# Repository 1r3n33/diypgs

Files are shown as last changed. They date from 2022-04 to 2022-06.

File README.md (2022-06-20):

# diypgs 🎮

The DIY portable game system.



# Electronics (schematics, PCB) 🪛🧰

Easy, cheap, and Arduino based...

### 👉 [**Making of the 1st board explained with pictures!**](./make/README.md) 📷

---

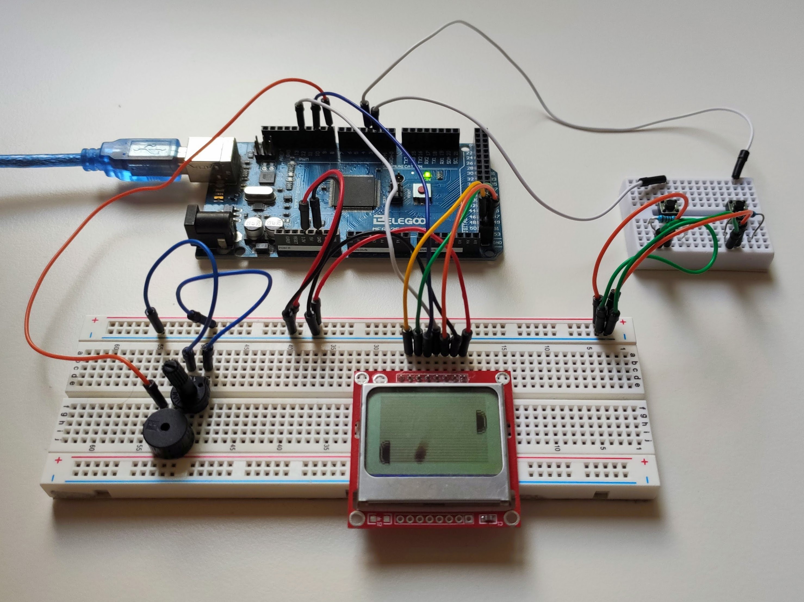
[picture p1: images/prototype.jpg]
Prototype

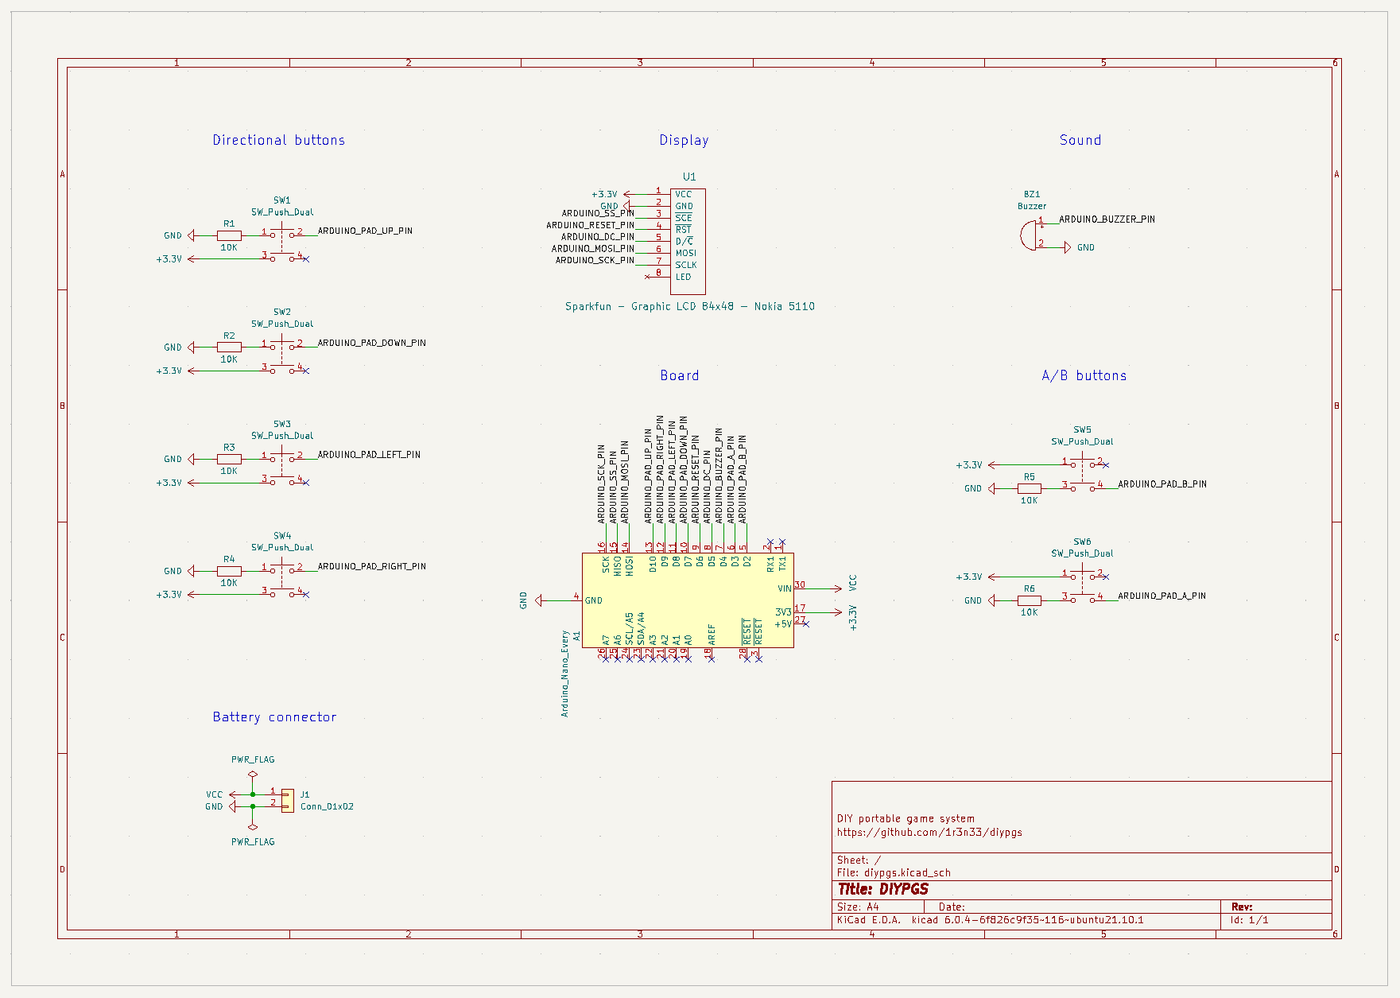
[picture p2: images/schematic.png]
Schematic

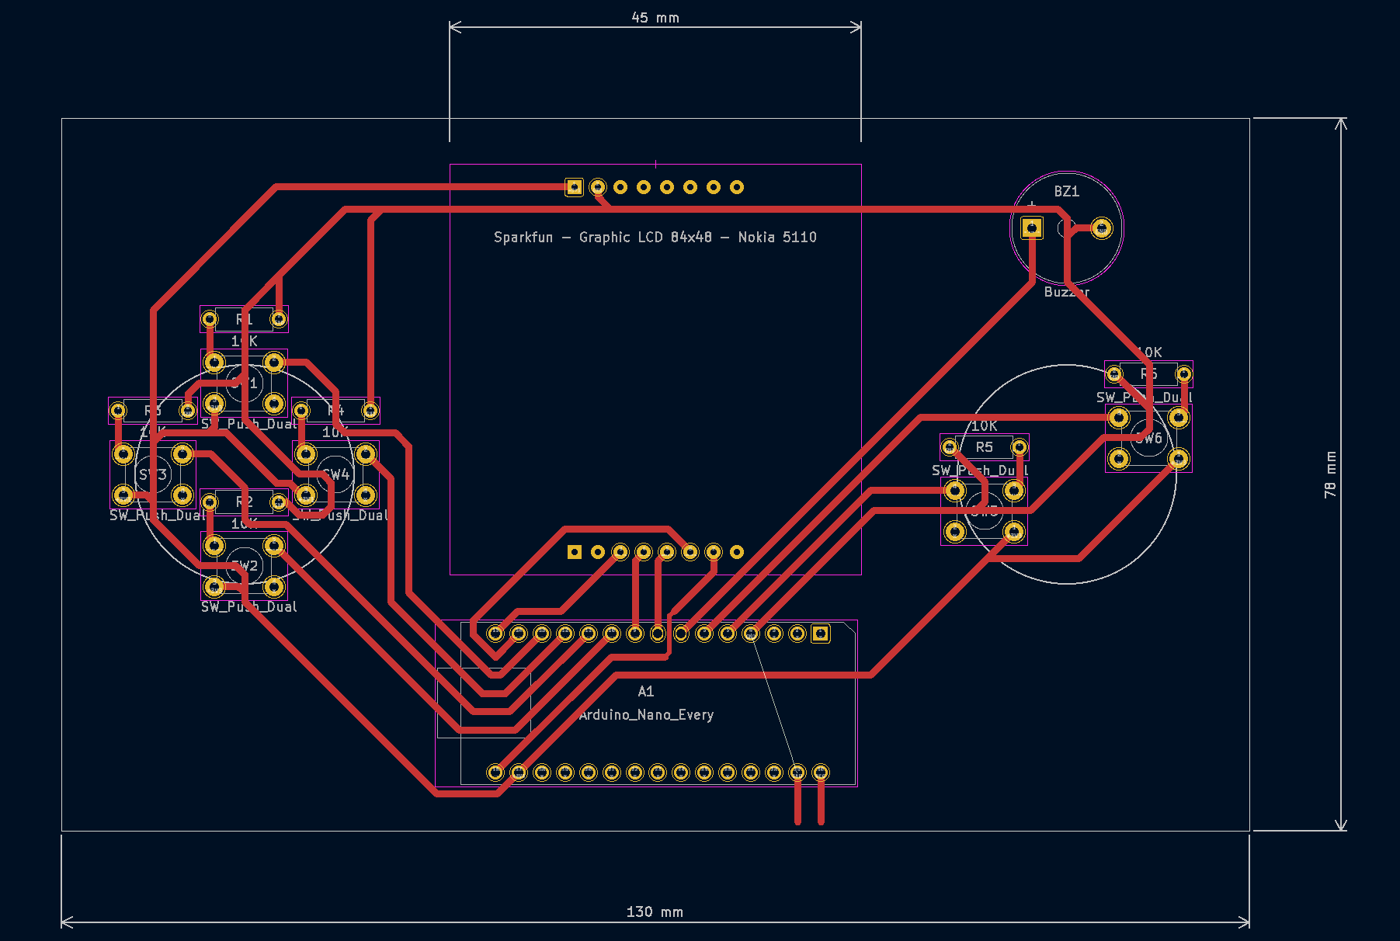
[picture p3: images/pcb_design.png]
PCB_Design

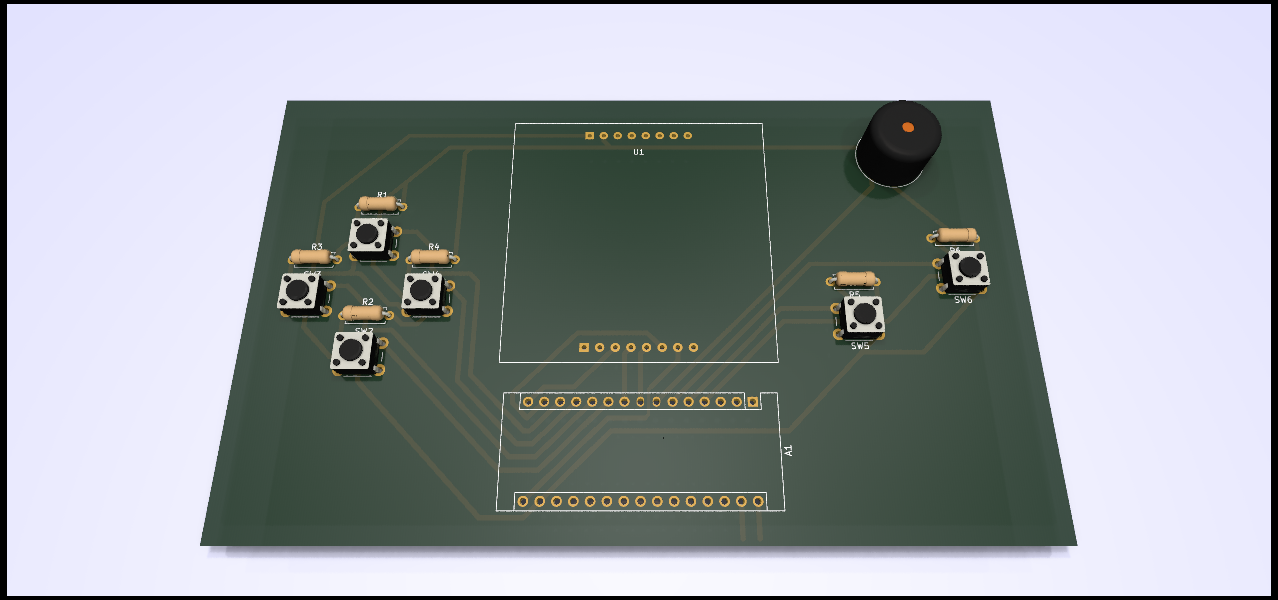
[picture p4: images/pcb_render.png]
PCB_Render


# Software (development kit & games) 🧑‍💻🤖

Develop your own games with provided SDK and example!

# 3D printing (case) 🚧👷

TBD

# Shop 🛒💸

If you are interested in getting one, please contact icaroulle+diypgs@gmail.com.

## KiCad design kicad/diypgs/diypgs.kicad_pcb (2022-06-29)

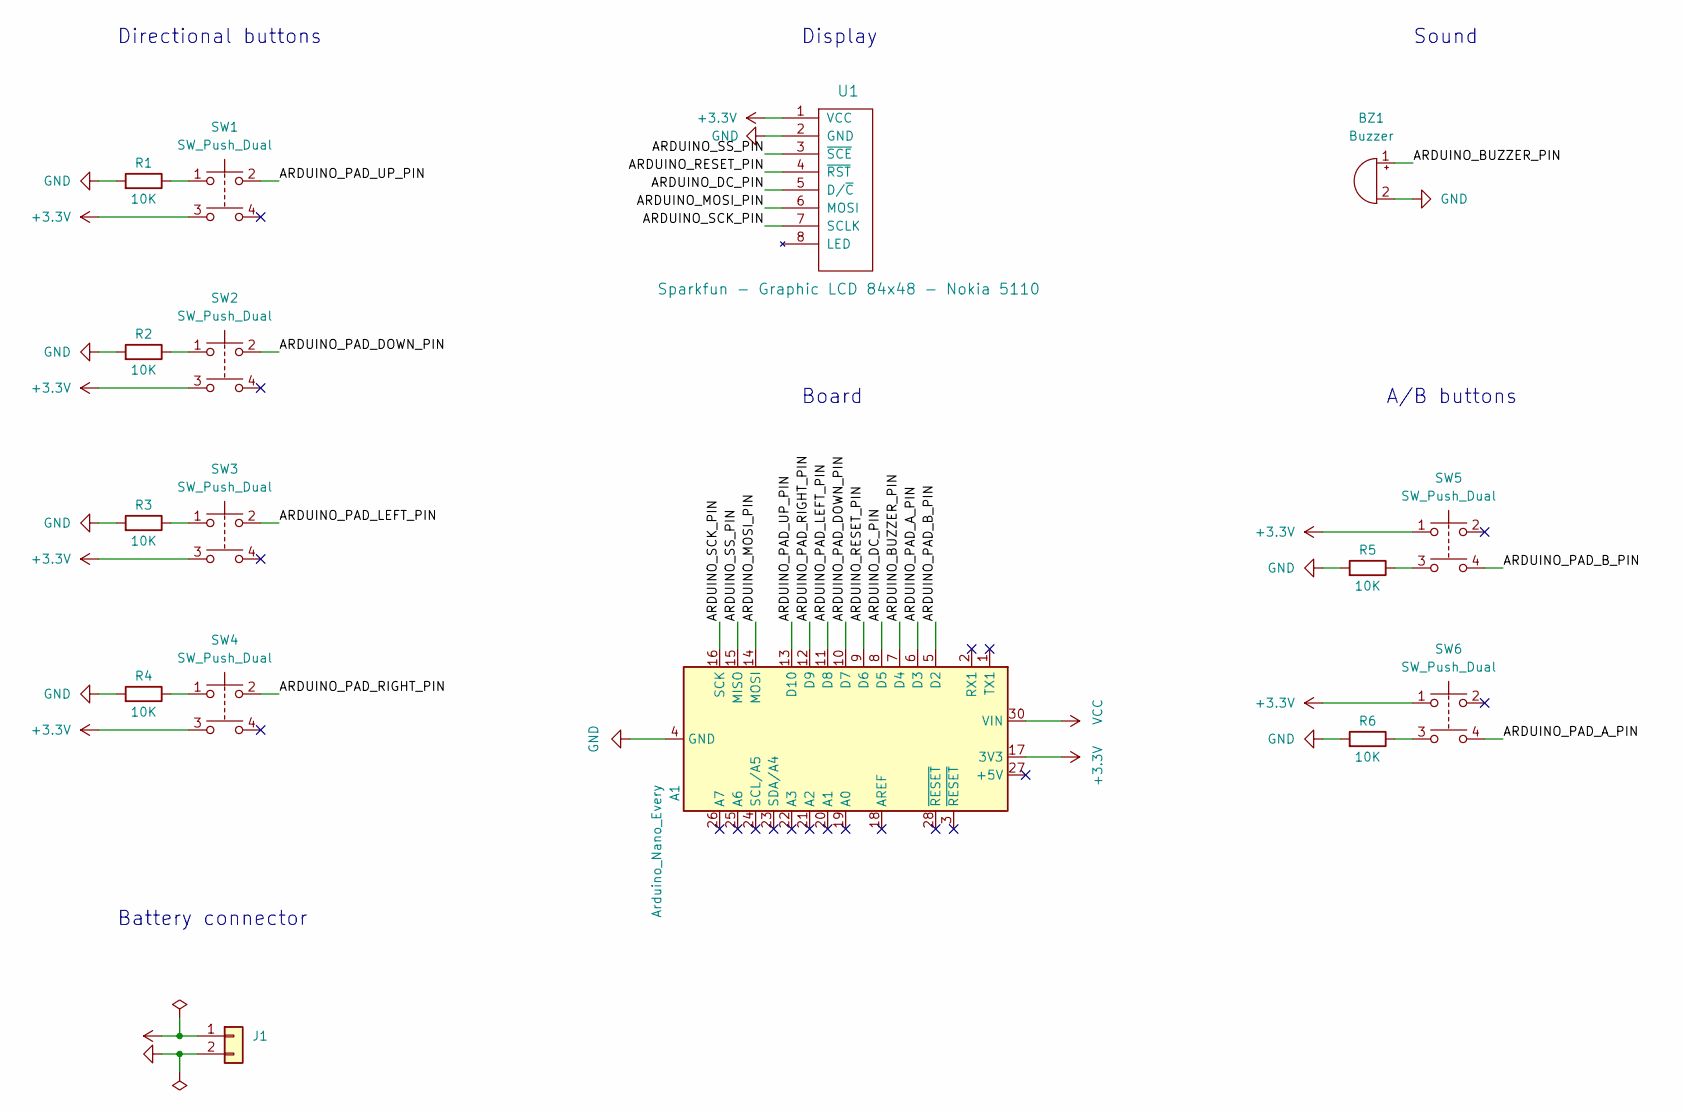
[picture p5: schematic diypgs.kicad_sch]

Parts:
A1: Arduino_Nano_Every; Arduino_Nano
BZ1: Buzzer; Buzzer_12x9.5RM7.6
J1: (no value)
R1, R2, R3, R4, R5, R6: 10K; R_Axial_DIN0207_L6.3mm_D2.5mm_P7.62mm_Horizontal
SW1, SW2, SW3, SW4, SW5, SW6: SW_Push_Dual; SW_PUSH_6mm_ALT
U1: Sparkfun - Graphic LCD 84x48 - Nokia 5110

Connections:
+3V3: A1.17 (3V3), SW1.3, SW2.3, SW3.3, SW4.3, SW5.1, SW6.1, U1.1 (VCC)
/ARDUINO_BUZZER_PIN: A1.7 (D4), BZ1.1 (-)
/ARDUINO_DC_PIN: A1.8 (D5), U1.5 (D/~C)
/ARDUINO_MOSI_PIN: A1.14 (MOSI), U1.6 (MOSI)
/ARDUINO_PAD_A_PIN: A1.6 (D3), SW6.4
/ARDUINO_PAD_B_PIN: A1.5 (D2), SW5.4
/ARDUINO_PAD_DOWN_PIN: A1.10 (D7), SW2.2
/ARDUINO_PAD_LEFT_PIN: A1.11 (D8), SW3.2
/ARDUINO_PAD_RIGHT_PIN: A1.12 (D9), SW4.2
/ARDUINO_PAD_UP_PIN: A1.13 (D10), SW1.2
/ARDUINO_RESET_PIN: A1.9 (D6), U1.4 (~RST)
/ARDUINO_SCK_PIN: A1.16 (SCK), U1.7 (SCLK)
/ARDUINO_SS_PIN: A1.15 (MISO), U1.3 (~SCE)
GND: A1.4 (GND), A1.29 (GND), BZ1.2 (+), R1.2, R2.2, R3.2, R4.2, R5.2, R6.2, U1.2 (GND)
unnamed: J1.1, J1.2
unnamed: R1.1, SW1.1
unnamed: R2.1, SW2.1
unnamed: R3.1, SW3.1
unnamed: R4.1, SW4.1
unnamed: R5.1, SW5.3
unnamed: R6.1, SW6.3
VCC: A1.30 (VIN)

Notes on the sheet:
Sound
Display
A/B buttons
Directional buttons
Battery connector
Board

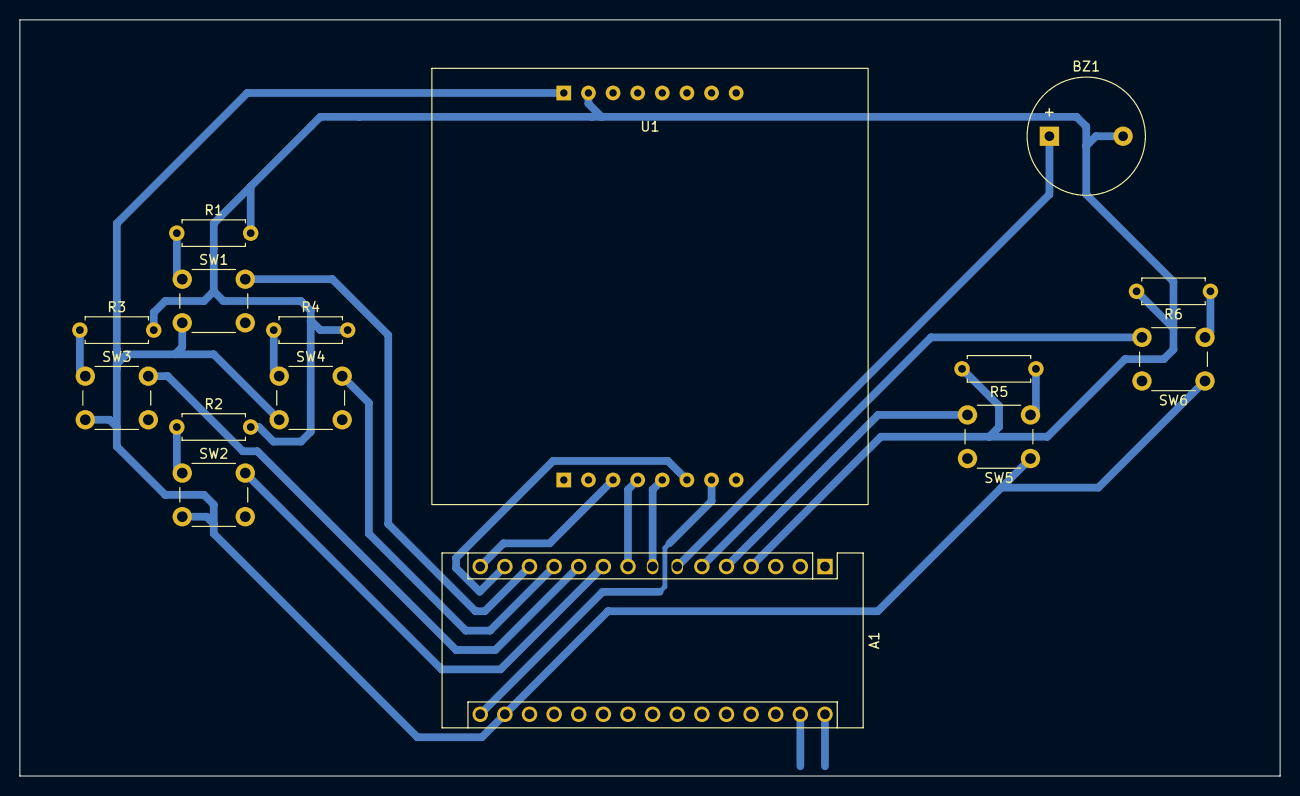
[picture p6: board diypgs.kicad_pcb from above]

Board: 2 copper layers, 130.0 x 78.0 mm, 15 parts (0 on the bottom side), 20 nets.

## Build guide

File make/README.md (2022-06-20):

# Making your own PCB

## Toner transfer

PCB circuit layer laser printed on glossy paper:  
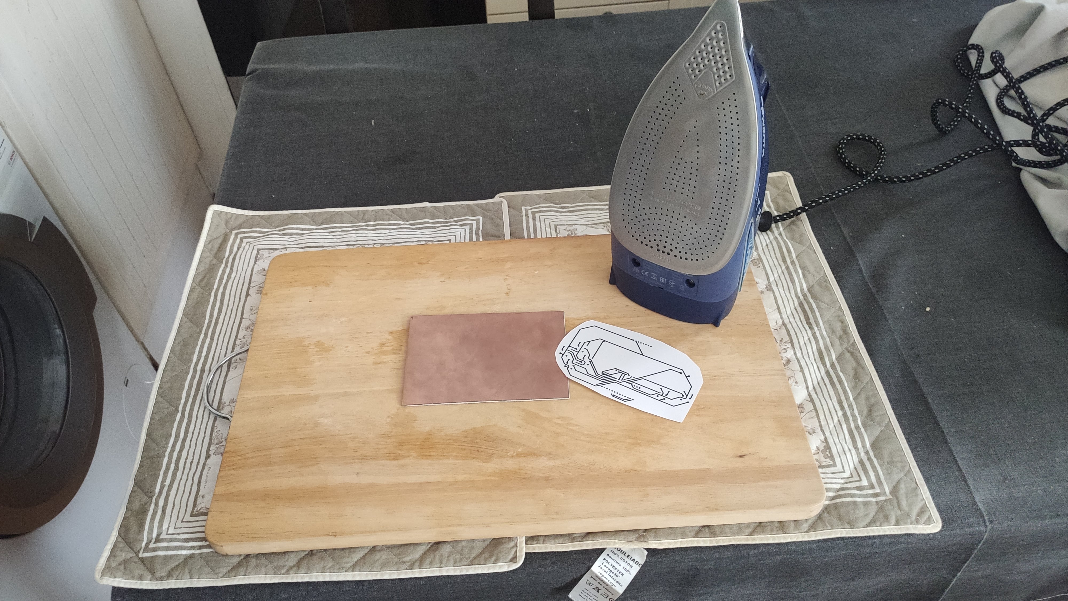
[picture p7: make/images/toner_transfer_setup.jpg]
TonerTransferSetup


Maximum heat and apply strong pressure to transfer toner (5 min.):
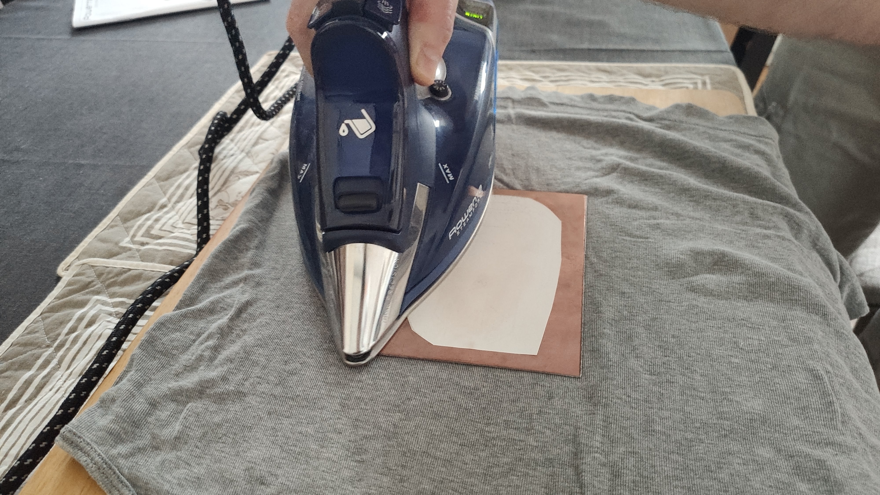
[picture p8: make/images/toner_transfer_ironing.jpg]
TonerTransferIroning


Water bath to remove the paper (10 min.):
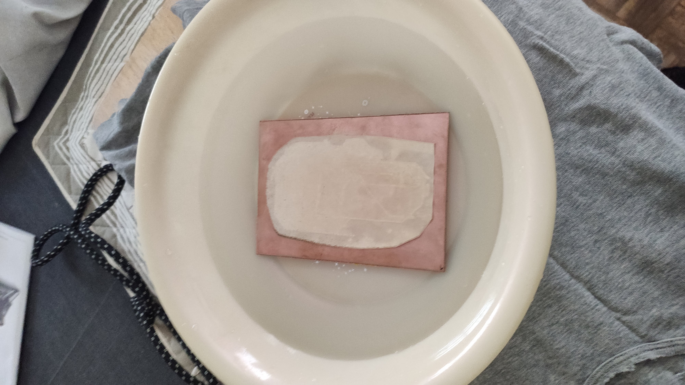
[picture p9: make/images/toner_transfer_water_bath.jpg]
TonerTransferWaterBath


Peel the paper gently:
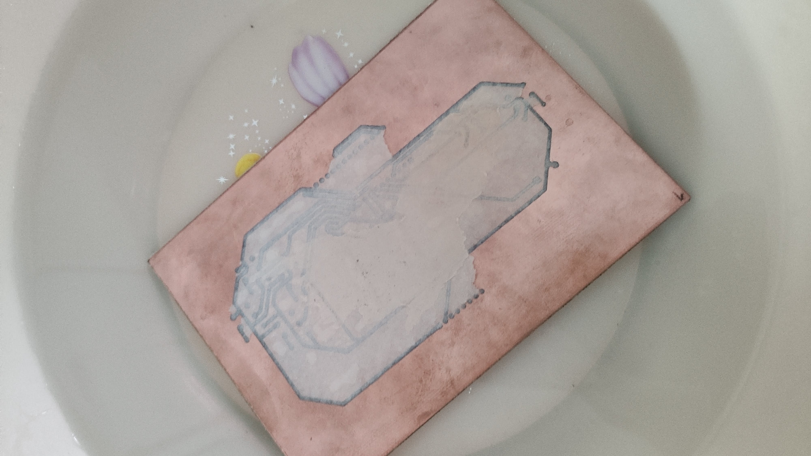
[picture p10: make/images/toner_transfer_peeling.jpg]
TonerTransferPeeling


Toner acts as a mask when chemically removing the copper:
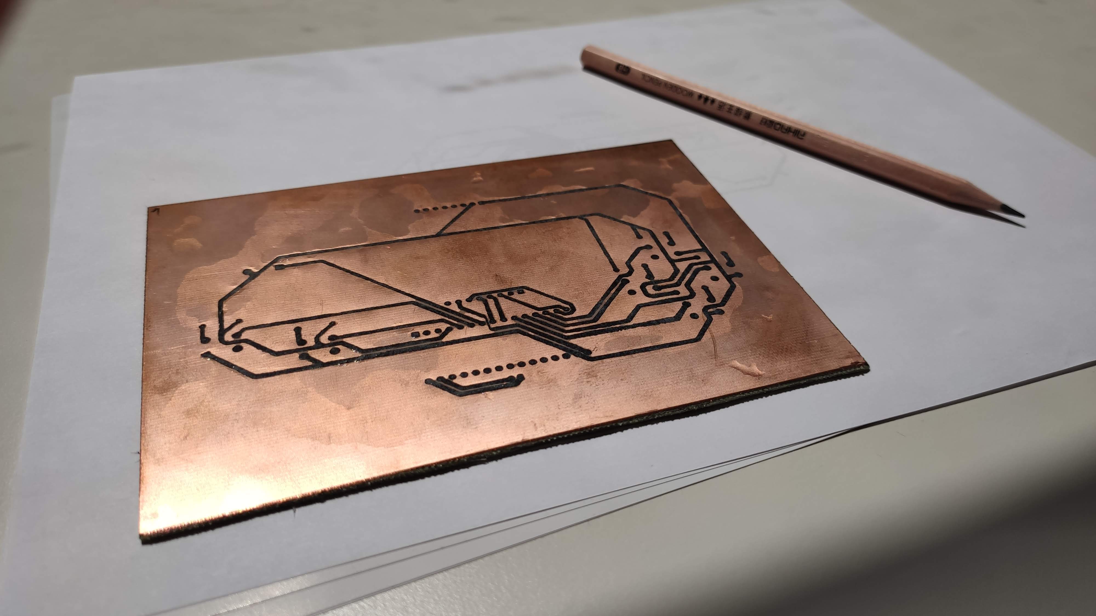
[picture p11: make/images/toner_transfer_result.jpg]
TonerTransferResult


## Etching

Bath the PCB in ferric chloride and gently agitate the solution in a well-ventilated area (45 min.):
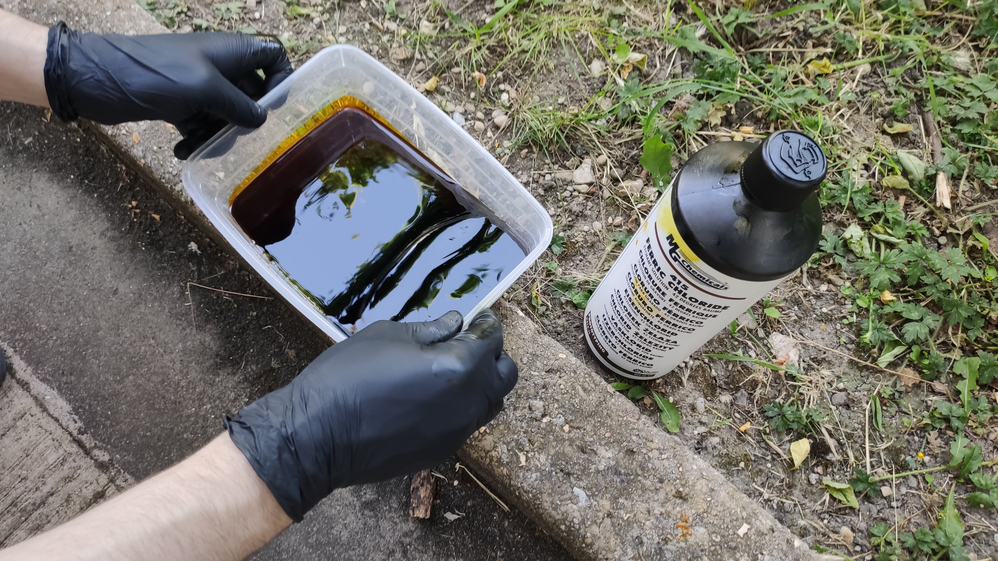
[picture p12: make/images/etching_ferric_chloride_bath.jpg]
EtchingFerricChlorideBath


Wash many times in water:
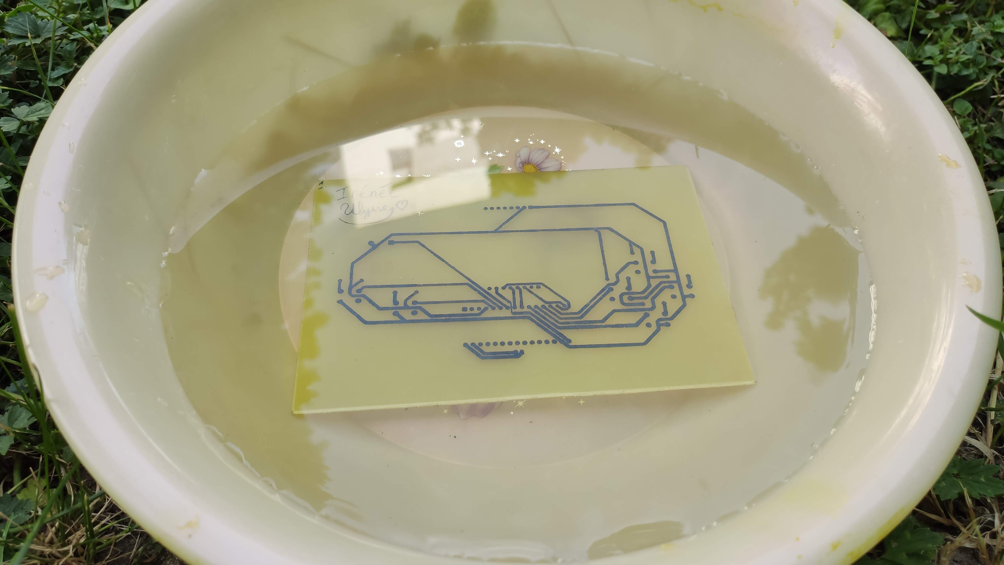
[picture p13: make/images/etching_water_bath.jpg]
EtchingWaterBatch


## Cleaning

Remove toner with acetone in a well-ventilated area:
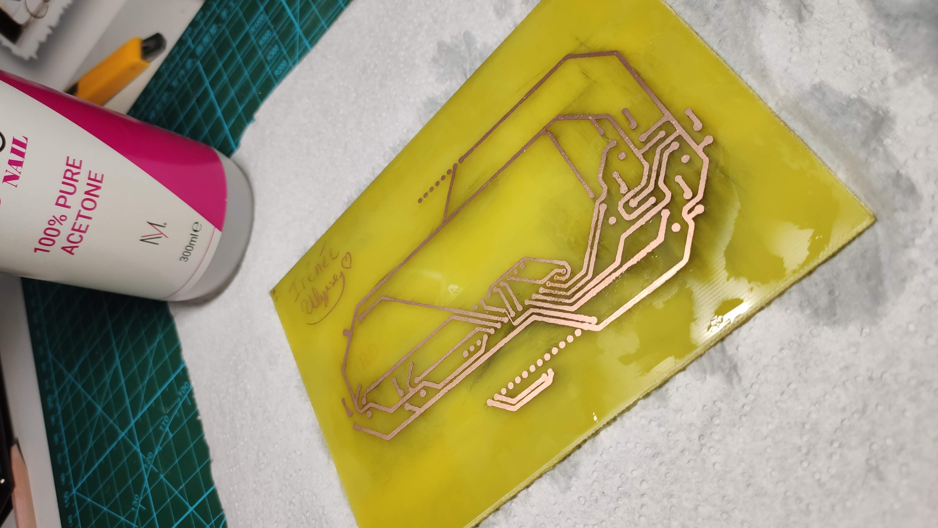
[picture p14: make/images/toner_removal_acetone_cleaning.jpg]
TonerRemovalAcetoneCleaning


Ready to be tested:
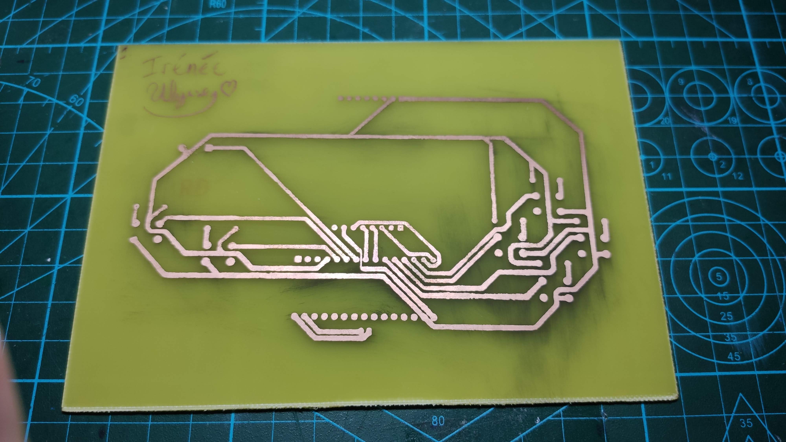
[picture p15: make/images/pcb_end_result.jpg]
PcbEndResult


## Testing

Checking and fixing short circuits:
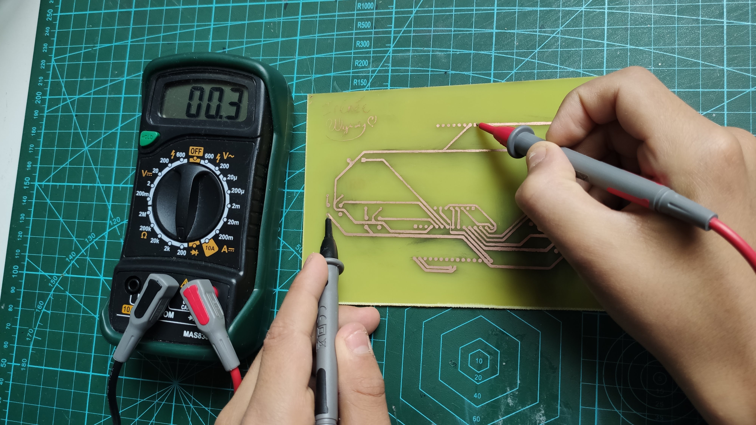
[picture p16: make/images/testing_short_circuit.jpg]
TestingShortCircuit


## Mounting & soldering

Getting ready to mount the board:
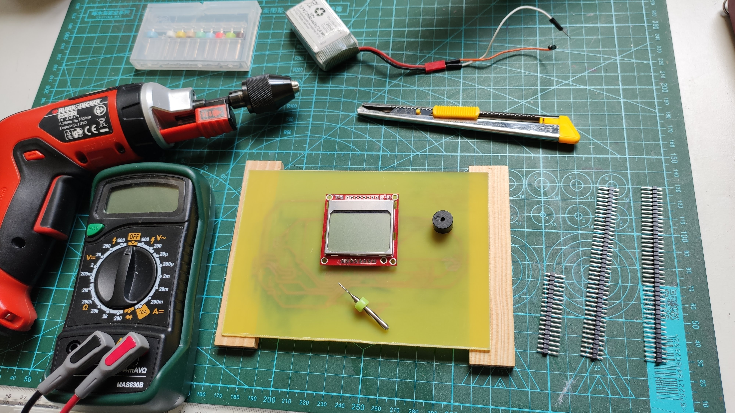
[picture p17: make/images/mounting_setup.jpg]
MountingSetup


Main components soldered:
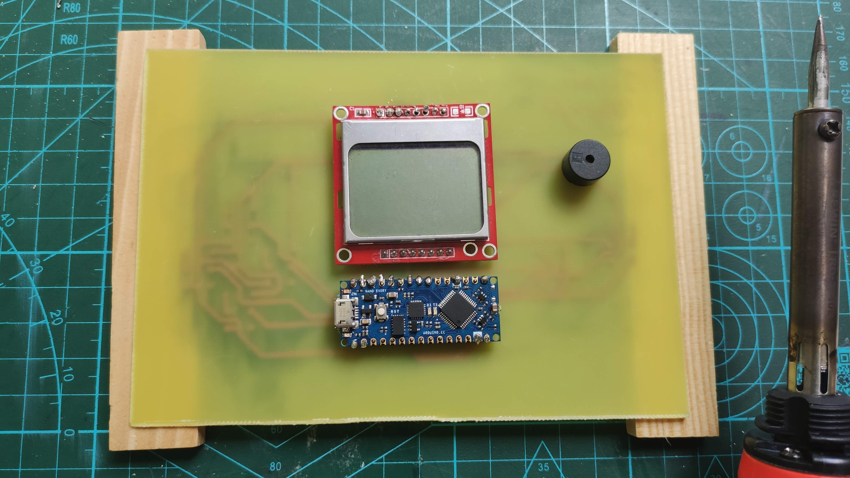
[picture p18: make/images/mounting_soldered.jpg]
MountingSoldered


Booting up:
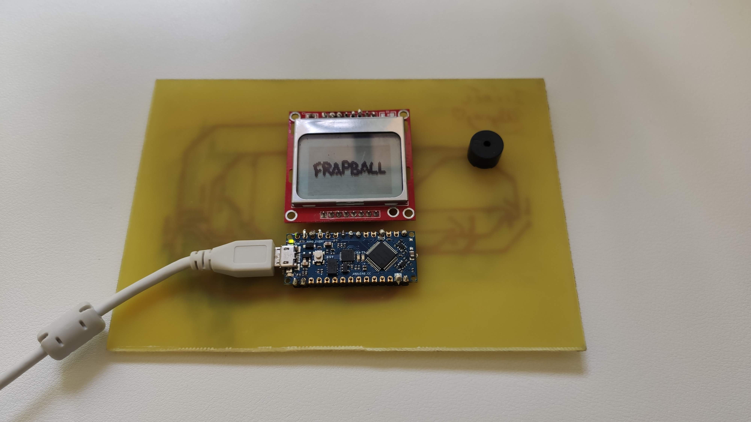
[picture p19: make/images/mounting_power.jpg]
MountingPower


## Playing

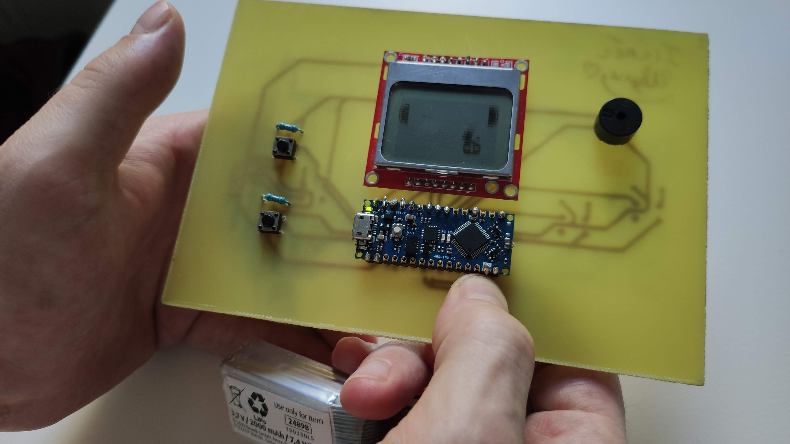
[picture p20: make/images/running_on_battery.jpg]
RunningOnBattery


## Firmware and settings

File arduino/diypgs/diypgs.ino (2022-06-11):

#include "src/hw/Buzzer.h"
#include "src/hw/Gamepad.h"
#include "src/hw/Pcd8544.h"

#include "src/sdk/Collision.h"

#include "src/game/Game.h"
#include "src/game/Titlescreen.h"

namespace
{
  constexpr uint32_t USEC_PER_FRAME = 1000000 / 30; // 30 Hz

  const hw::Pcd8544 graphics(5, 6, 12);
  const hw::Buzzer audio(4);
  const hw::Gamepad controller(10, 7, 8, 9, 3, 2);

  game::Titlescreen titlescreen(graphics, audio, controller);
  game::Game game_(graphics, audio, controller);

  game::World *currentWorld = nullptr;
}

void setup()
{
  srand(micros());

  graphics.setup();
  audio.setup();
  controller.setup();

  titlescreen.setNextWorld(&game_);
  game_.setNextWorld(&titlescreen);

  currentWorld = &titlescreen;
  currentWorld->setup();
}

void loop()
{
  const uint32_t start = micros();

  game::World::State state = currentWorld->update();
  graphics.render();

  game::World *nextWorld = nullptr;
  switch (state)
  {
  case game::World::State::NEXT:
    nextWorld = currentWorld->getNextWorld();
    nextWorld->setup();
    currentWorld = nextWorld;
    break;

  default:
    break;
  }

  // Target 30 fps.
  // Cannot use delayMicroseconds because the largest value that will produce an accurate delay is 16383.
  // https://www.arduino.cc/reference/en/language/functions/time/delaymicroseconds/
  const uint32_t elapsed = micros() - start;
  if (elapsed < USEC_PER_FRAME)
  {
    delay((USEC_PER_FRAME - elapsed) / 1000);
  }
}

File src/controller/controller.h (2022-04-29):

#ifndef CONTROLLER_H
#define CONTROLLER_H

class Controller
{
private:
    uint8_t pins[6];

public:
    static const uint8_t BUTTON_UP = 0x01;
    static const uint8_t BUTTON_DOWN = 0x02;
    static const uint8_t BUTTON_LEFT = 0x04;
    static const uint8_t BUTTON_RIGHT = 0x08;
    static const uint8_t BUTTON_A = 0x10;
    static const uint8_t BUTTON_B = 0x20;

    Controller()
    {
    }

    void setup(const uint8_t button_up_pin,
               const uint8_t button_down_pin,
               const uint8_t button_left_pin,
               const uint8_t button_right_pin,
               const uint8_t button_a_pin,
               const uint8_t button_b_pin)
    {
        pins[0] = button_up_pin;
        pins[1] = button_down_pin;
        pins[2] = button_left_pin;
        pins[3] = button_right_pin;
        pins[4] = button_a_pin;
        pins[5] = button_b_pin;

        pinMode(pins[0], INPUT);
        pinMode(pins[1], INPUT);
        pinMode(pins[2], INPUT);
        pinMode(pins[3], INPUT);
        pinMode(pins[4], INPUT);
        pinMode(pins[5], INPUT);
    }

    uint8_t get() const
    {
        uint8_t out = 0;
        out |= digitalRead(pins[0]) == HIGH ? BUTTON_UP : 0;
        out |= digitalRead(pins[1]) == HIGH ? BUTTON_DOWN : 0;
        out |= digitalRead(pins[2]) == HIGH ? BUTTON_LEFT : 0;
        out |= digitalRead(pins[3]) == HIGH ? BUTTON_RIGHT : 0;
        out |= digitalRead(pins[4]) == HIGH ? BUTTON_A : 0;
        out |= digitalRead(pins[5]) == HIGH ? BUTTON_B : 0;
        return out;
    }
};

#endif

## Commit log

2022-04-03 Use SPI
2022-04-09 Add framebuffer
2022-04-23 Ball collides with paddles
    [ball.h]
2022-05-01 Fix loop to 30Hz
2022-05-09 Add KiCad project
    [diypgs.kicad_pcb, diypgs.kicad_sch]
2022-05-11 Fix bounce on paddle
    [ball.h]
2022-05-14 Add PCB design
    [diypgs.kicad_pcb, diypgs.kicad_sch]
2022-05-16 Fix button pad number
    [diypgs.kicad_pcb, diypgs.kicad_sch]
2022-05-17 Add PCB tracks
    [diypgs.kicad_pcb, diypgs.kicad_sch]
2022-05-17 Fix ball bouncing back into the game
    [ball.h]
2022-05-20 Fix screen symbol and footprint
    [diypgs.kicad_pcb, diypgs.kicad_sch]
2022-05-21 Move arduino code to dedicated folder
2022-05-22 All tracks routed
    [diypgs.kicad_pcb, diypgs.kicad_sch]
2022-05-27 Fix PCB design
    [diypgs.kicad_pcb]
2022-05-28 Add JST connector
    [diypgs.kicad_pcb, diypgs.kicad_sch]
2022-05-28 Add arduino:avr:nano build target
2022-06-18 Recipe to make PCB
2022-06-23 Board modification after initial PCB prototype
    [diypgs.kicad_pcb]
2022-06-24 Thinner PCB tracks
    [diypgs.kicad_pcb]
2022-06-29 Move tracks to background layer
    [diypgs.kicad_pcb]
